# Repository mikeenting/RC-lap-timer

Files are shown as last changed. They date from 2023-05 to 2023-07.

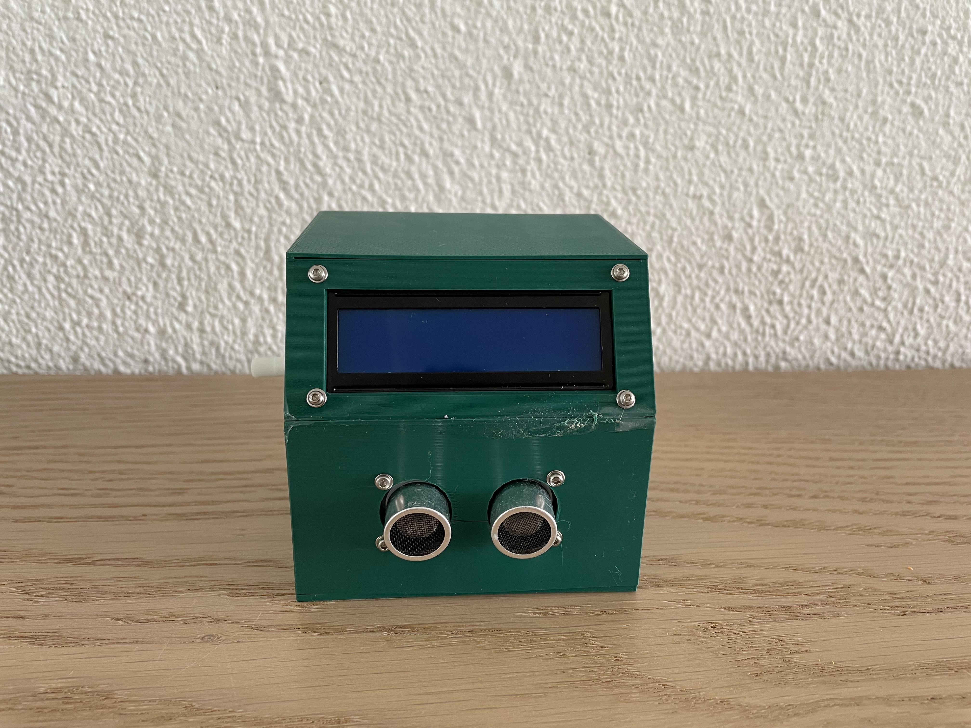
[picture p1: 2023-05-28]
img/IMG_1788.jpeg

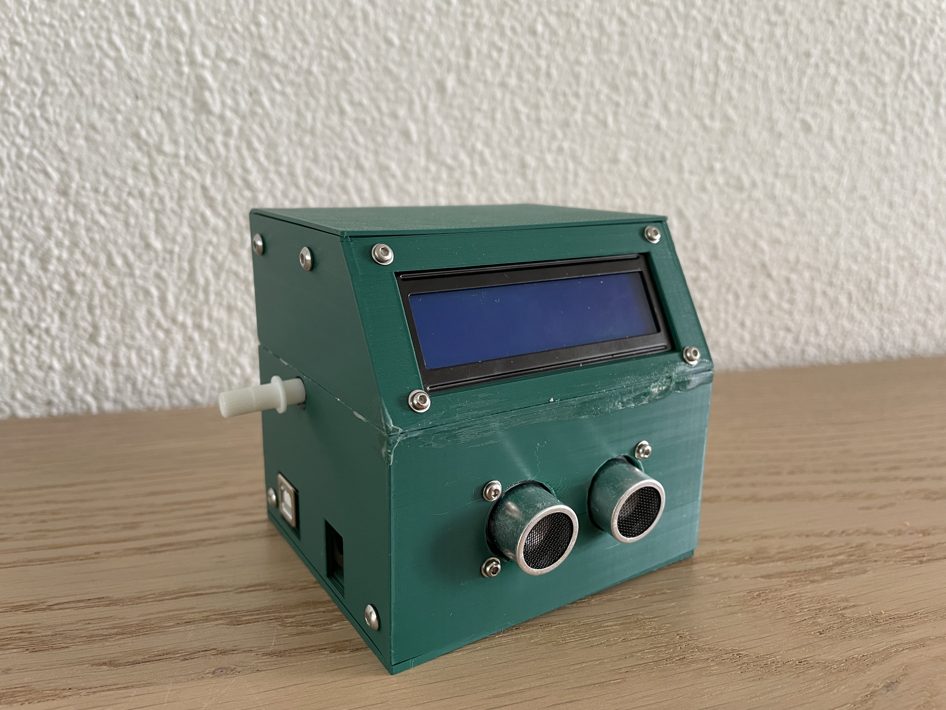
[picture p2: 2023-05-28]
img/IMG_1787.jpeg

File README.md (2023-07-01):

# RC-lap-timer
## Description
This projects uses an Arduino to track the lap times of an RC car. It times the lap, and keeps track of the fastest registered lap. It is portable and can be powered with a 9V battery. See [this link](https://www.thingiverse.com/thing:6049245) to find the project on Thingiverse.

## Demo
Demo (https://youtu.be/-q12BmalPtk)

## Required materials
See component list [here](https://github.com/mikeenting/RC-lap-timer/blob/main/laptimer_component_list.csv)

## Assembly
1. Download [this program](https://github.com/mikeenting/RC-lap-timer/blob/main/laptimer/laptimer.ino) and upload it to your Arduino
2. Download, slice and print all files in [this folder](https://github.com/mikeenting/RC-lap-timer/blob/main/3d_designs) (see suggested printer settings below)
3. Use M3 heat set insert to connect arduino to the floor
4. Connect ultrasonic sensor to middle bottom
5. Connect floor to middle bottom using M3 heat set inserts
6. Use hot glue to connect potentiometer to middle bottom
7. Connect LCD to middle top
8. Wire up Arduino with all parts, according to [this circuit view](https://github.com/mikeenting/RC-lap-timer/blob/main/laptimer_circuit_view.png)
9. Connect middle bottom and top using M3 heat set inserts
10. Attach the lid using M3 heat set inserts
11. Power up the Arduino and you're good to go!

## Printer Settings
I printed with a Creality Ender 3 V2, using 1.75mm PLA and the following settings:
- Floor:
    - Print regular side down
    - Profile: 0.2
    - Infill: 60%
    - No support required
- Middle Bottom:
    - Print upside down
    - Profile: 0.2
    - Infill: 60%
    - No support required
- Middle Top:
    - Print regular side down
    - Profile: 0.2
    - Infill: 60%
    - Print with support (optional: use support blocker to prevent unnecessary support to be printed in the holes)
- Lid:
    - Print regular side down
    - Profile: 0.2
    - Infill: 60%
    - No support required

------
### Inspiration from
- https://github.com/beaver-pc/RC-Lap-Timer/blob/master/Lap_Timer.ino
- https://create.arduino.cc/projecthub/abdularbi17
- https://www.thingiverse.com/thing:2813169

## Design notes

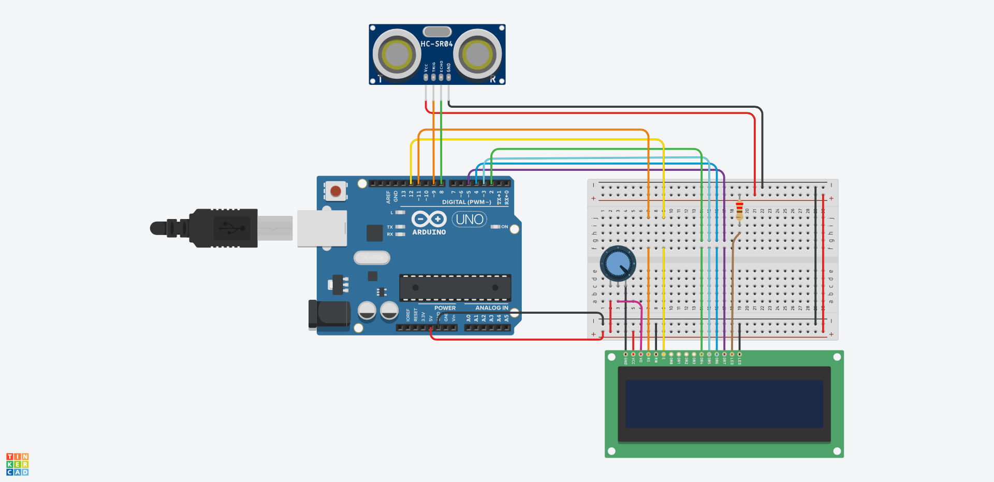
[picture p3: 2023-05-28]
laptimer_circuit_view.png

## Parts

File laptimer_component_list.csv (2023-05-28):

Name | Quantity | Component
U2 | 1 | Arduino Uno R3
U3 | 1 | LCD 16 x 2
Rpot1 | 1 | 250 kΩ Potentiometer
R1 | 1 | 220 Ω Resistor
DIST1 | 1 | Ultrasonic Distance Sensor

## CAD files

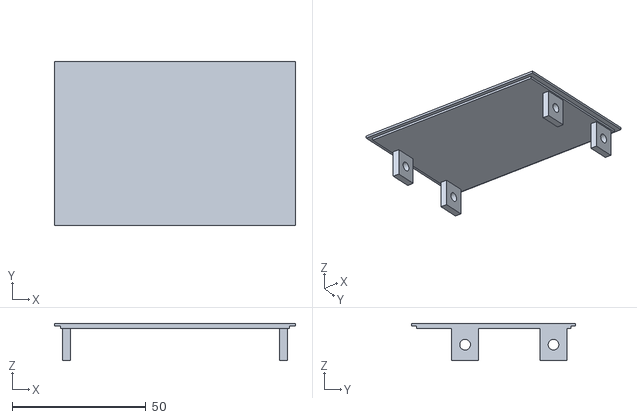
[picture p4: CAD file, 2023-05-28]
3d_designs/laptimer_lid.stl
90.0 x 61.2 x 14.0

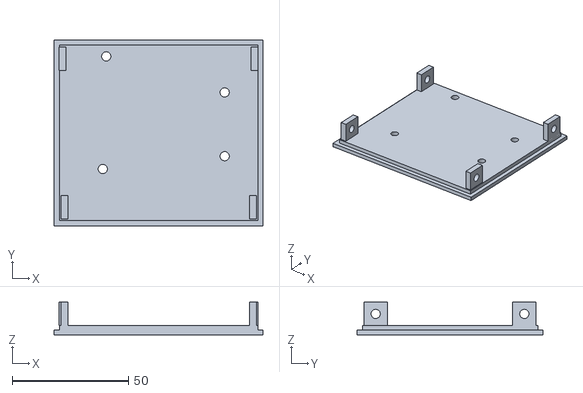
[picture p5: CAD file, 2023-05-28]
3d_designs/laptimer_floor.stl
90.0 x 80.0 x 14.0

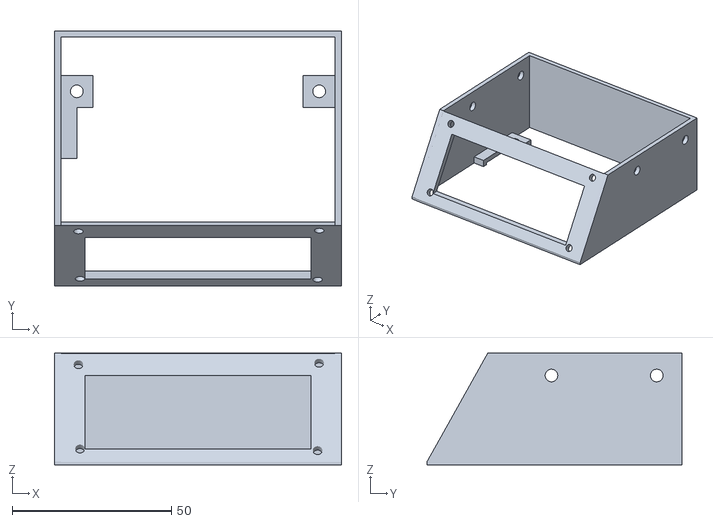
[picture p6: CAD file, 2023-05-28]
3d_designs/laptimer_middle_top.stl
90.0 x 80.1 x 35.0

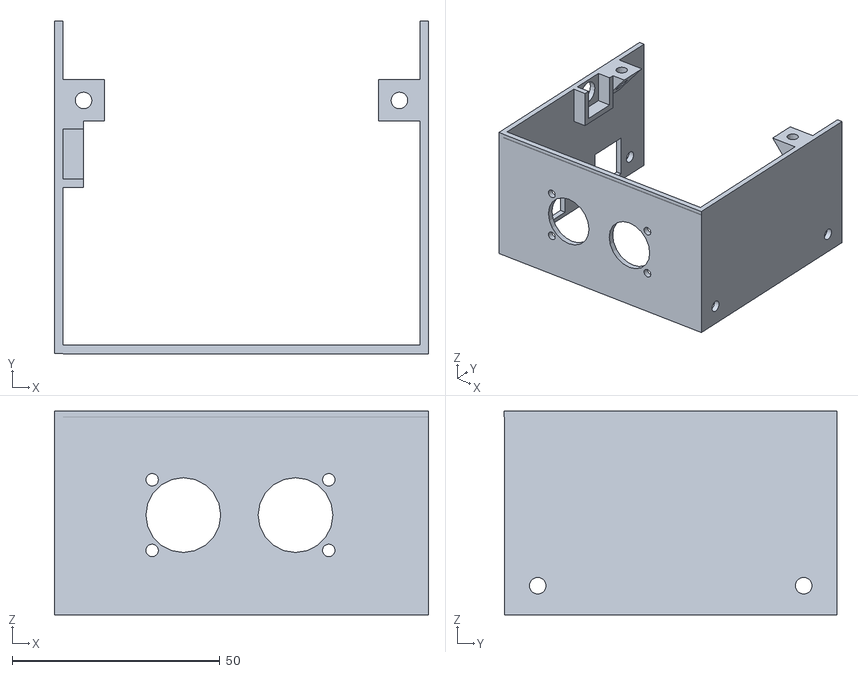
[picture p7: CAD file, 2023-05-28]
3d_designs/laptimer_middle_bottom.stl
90.0 x 80.1 x 49.0

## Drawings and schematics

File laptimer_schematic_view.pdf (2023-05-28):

A

1 | 2 | 3 | 4 | 5 | 6

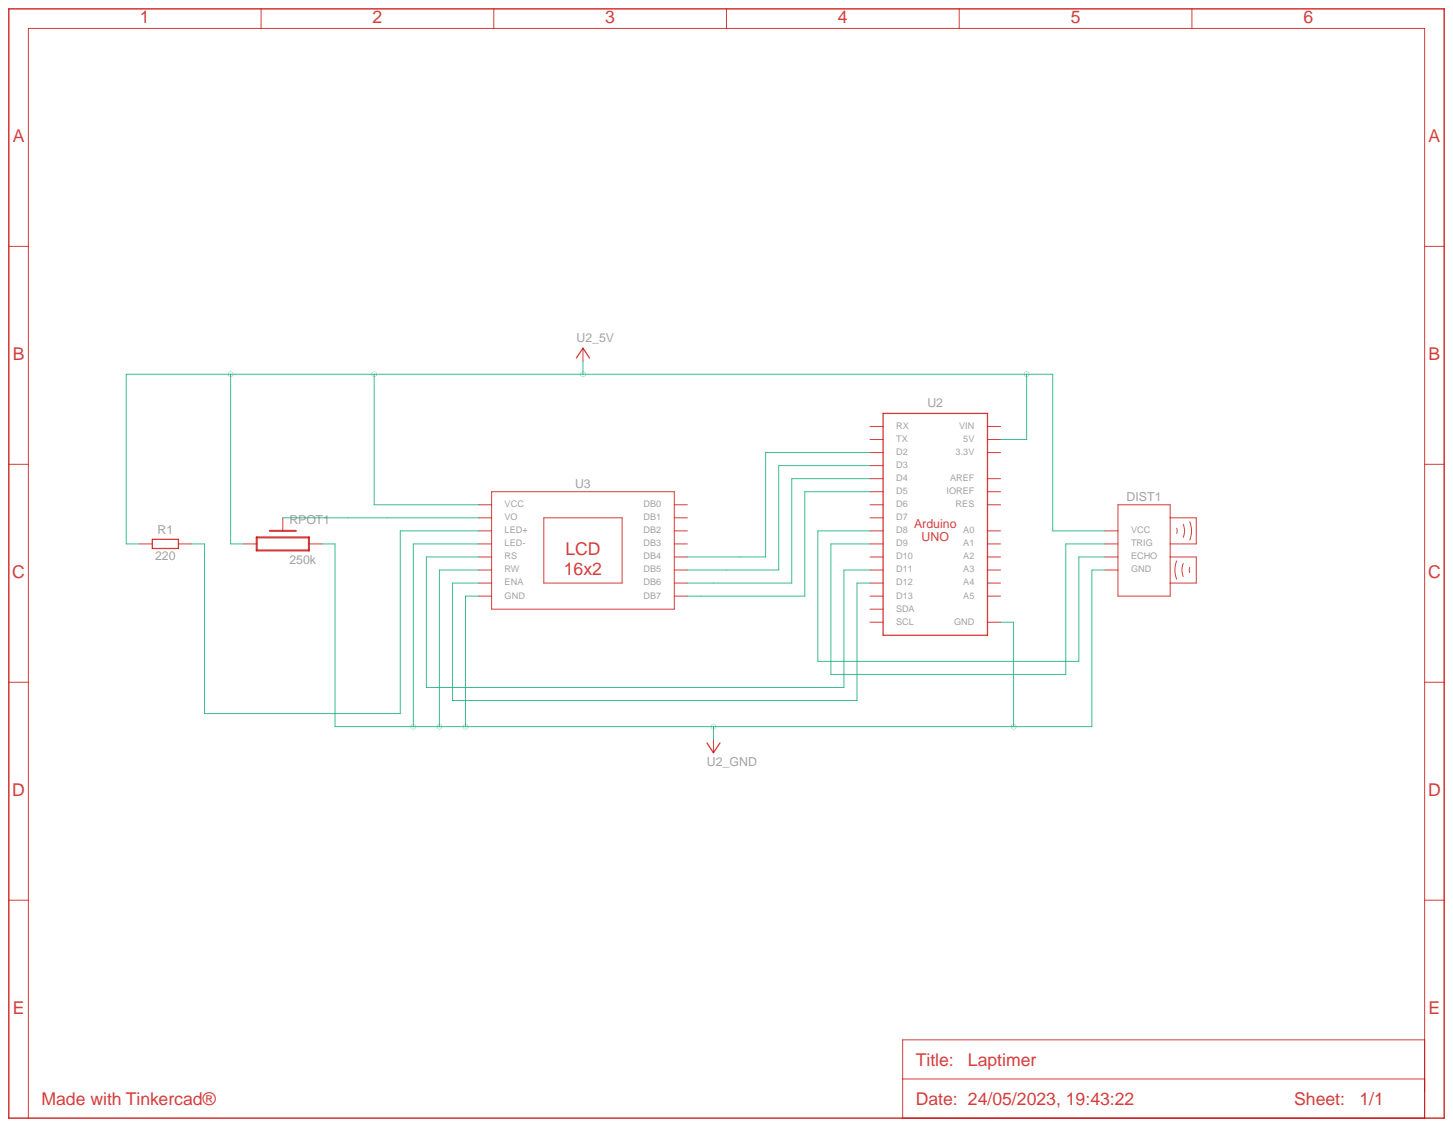
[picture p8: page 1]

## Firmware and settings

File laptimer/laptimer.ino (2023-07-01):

// This includes the LiquidCrystal library, which is used to control the LCD display.
#include <LiquidCrystal.h>

#define echoPin 8  // attach pin D2 Arduino to pin Echo of HC-SR04
#define trigPin 9  // attach pin D3 Arduino to pin Trig of HC-SR04

// Adaptive variables
int maxdistance = 15;  // variable for setting the default distance in centimeters measured by the sensor
int minlaptime = 5;    // variable for setting the minimum number of seconds a lap should take (to prevent invalid laps from being registered)
int maxlaps = 3;      // variable for setting the maximum number of laps the timer should register. Do not set higher than 99, to prevent the lap numbers from rolling off the LCD screen.

// Defines variables
long duration;      // variable for the duration of sound wave travel
int distance;       // variable for the distance measurement
int lap = 0;        // variable for counting the amount of laps
int recordlap = 1;  // variable for counting which lap the fastest lap was set
double laptime = 0;
double recordtime = 0;
double livelaptime = 0;
double totaltime_seconds;
double a;
double c;
double d;
double e;
// Define LCD variables
int rs = 11;
int en = 12;
int d4 = 2;
int d5 = 3;
int d6 = 4;
int d7 = 5;
LiquidCrystal lcd(rs, en, d4, d5, d6, d7);

// Finish Flag
byte flag1[8] = {
  B11111,
  B00000,
  B11111,
  B00000,
  B11111,
  B00000,
  B11111,
  B00000
};

byte flag2[8] = {
  B00000,
  B11111,
  B00000,
  B11111,
  B00000,
  B11111,
  B00000,
  B11111
};

void setup() {
  // Setup ultrasonic sensor HC-SR04
  pinMode(trigPin, OUTPUT);  // Sets the trigPin as an OUTPUT
  pinMode(echoPin, INPUT);   // Sets the echoPin as an INPUT

  // Setup serial monitor
  Serial.begin(9600);                             // // Serial Communication is starting with 9600 of baudrate speed
  Serial.println("Welcome to Arduino laptimer");  // print some text in Serial Monitor

  // Setup LCD
  lcd.begin(16, 2);               // set up number of columns and rows
  lcd.setCursor(0, 0);            // move cursor to   (0, 0)
  lcd.print("Welcome to");        // print message at (0, 0)
  lcd.setCursor(0, 1);            // move cursor to   (0, 0)
  lcd.print("Arduino laptimer");  // print message at (0, 0)
  delay(4000);
  lcd.clear();
  lcd.setCursor(0, 0);
  lcd.print("Start racing to");
  lcd.setCursor(0, 1);
  lcd.print("get started!");

  lcd.createChar(0, flag1);  // Creates custom character and stores it in the LCD's memory
  lcd.createChar(1, flag2);  // Creates second custom character
}
void loop() {
  delay(10);
  // Clears the trigPin condition
  digitalWrite(trigPin, LOW);
  delayMicroseconds(2);
  // Sets the trigPin HIGH (ACTIVE) for 10 microseconds
  digitalWrite(trigPin, HIGH);
  delayMicroseconds(10);
  digitalWrite(trigPin, LOW);
  // Reads the echoPin, returns the sound wave travel time in microseconds
  duration = pulseIn(echoPin, HIGH);
  // Calculating the distance
  distance = duration * 0.034 / 2;  // Speed of sound wave divided by 2 (go and back)

  // This loop is used to wait for the first lap to start.
  // It continuously measures the distance until the distance is less than maxdistance, indicating that the first lap has started.
  while (lap < 1) {
    lcd.setCursor(0, 0);
    lcd.print("Start racing to");
    lcd.setCursor(0, 1);
    lcd.print("get started!");
    delay(10);
    // Clears the trigPin condition
    digitalWrite(trigPin, LOW);
    delayMicroseconds(2);
    // Sets the trigPin HIGH (ACTIVE) for 10 microseconds
    digitalWrite(trigPin, HIGH);
    delayMicroseconds(10);
    digitalWrite(trigPin, LOW);
    // Reads the echoPin, returns the sound wave travel time in microseconds
    duration = pulseIn(echoPin, HIGH);
    // Calculating the distance
    distance = duration * 0.034 / 2;  // Speed of sound wave divided by 2 (go and back)
    if (distance < maxdistance) {
      lap++;
      a = millis();
      e = millis();
    }
  }

  while (lap <= maxlaps) {
    // Clears the trigPin condition
    digitalWrite(trigPin, LOW);
    delayMicroseconds(2);
    // Sets the trigPin HIGH (ACTIVE) for 10 microseconds
    digitalWrite(trigPin, HIGH);
    delayMicroseconds(10);
    digitalWrite(trigPin, LOW);
    // Reads the echoPin, returns the sound wave travel time in microseconds
    duration = pulseIn(echoPin, HIGH);
    // Calculating the distance
    distance = duration * 0.034 / 2;  // Speed of sound wave divided by 2 (go and back)


    // Display current race time to display
    d = millis();
    c = millis();
    totaltime_seconds = (d - e) / 1000;
    livelaptime = (c - a) / 1000;
    lcd.clear();
    lcd.setCursor(0, 0);
    lcd.print("Lap:");
    lcd.setCursor(6, 0);
    lcd.print(lap);
    lcd.setCursor(0, 1);
    lcd.print("Time:");
    lcd.setCursor(6, 1);
    lcd.print(livelaptime);
    delay(10);

    // Lap timer
    // This conditional block is executed when the distance is less than maxdistance, indicating that a lap has ended.
    // It then checks whether the lap time is more than the minimum lap time.
    // If it is, it updates the record time if necessary, increments the lap count, and displays the lap time and record time on the LCD.
    if (distance < maxdistance) {
      c = millis();
      laptime = (c - a) / 1000;
      if (laptime > minlaptime) {
        if (recordtime == 0) {
          recordtime = laptime;
        }
        if (laptime < recordtime) {
          recordtime = laptime;
          recordlap = lap;
        }

        Serial.print("Lap: ");
        Serial.print(lap);
        Serial.print("\t\t");
        Serial.print("Laptime: ");
        Serial.print(laptime);
        Serial.print("\t\t");
        Serial.print("Lap record: ");
        Serial.print(recordtime);
        Serial.print("\t\t");
        Serial.print("Total time: ");
        Serial.println(totaltime_seconds);
        a = millis();
        // Write information to LCD Display
        lcd.clear();
        lcd.setCursor(0, 0);  // move cursor to   (0, 0)
        lcd.print("Time:");
        lcd.setCursor(6, 0);
        lcd.print(laptime);
        lcd.setCursor(0, 1);
        lcd.print("Rec:");
        lcd.setCursor(6, 1);
        lcd.print(recordtime);
        lcd.setCursor(13, 0);
        lcd.print("L");
        lcd.setCursor(14, 0);
        lcd.print(lap);
        lcd.setCursor(13, 1);
        lcd.print("L");
        lcd.setCursor(14, 1);
        lcd.print(recordlap);
        delay(3000);
        lcd.clear();
        lap++;
        if (lap == 11) {
          Serial.print("Average time per lap over past 10 laps:");
          Serial.print("\t\t");
          Serial.println(totaltime_seconds / 10);
        }
      }
    }
  }
  while (lap > maxlaps) {
    // Display flag pattern on the first half of the LCD
    for (int i = 0; i < 2; i++) {    // For each row
      for (int j = 0; j < 8; j++) {  // For each column in the first half
        lcd.setCursor(j, i);
        if (j % 2 == i % 2) {
          lcd.write((uint8_t)0);
        } else {
          lcd.write((uint8_t)1);
        }
      }
    }

    // Display 'Finish' and fastest time on the second half of the LCD
    lcd.setCursor(9, 0);  // Set cursor at 9th column of the first row
    lcd.print("Finish!");
    delay(3000);
    lcd.clear();
    lcd.setCursor(0, 0);
    lcd.print("Record:");
    lcd.setCursor(0, 1);
    lcd.print(recordtime);
    lcd.setCursor(13, 1);
    lcd.print("L");
    lcd.setCursor(14, 1);
    lcd.print(recordlap);
    delay(3000);
    lcd.clear();
  }
}

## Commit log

2023-05-28 Added 3D printeable case, print instructions and assembly steps in readme
    [laptimer_component_list.csv, laptimer_floor.stl, laptimer_lid.stl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]
2023-06-27 Improved script by adding a finish message, and fixing a bug where the number of laps fell off the LCD screen
    [laptimer.ino]
